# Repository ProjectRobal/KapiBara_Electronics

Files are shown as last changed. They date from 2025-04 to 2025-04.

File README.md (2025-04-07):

# KapiBara Electronics Design

That repository holds all the electronics for KapiBara robot. Everything was designed using KiCAD software.

## Boards

- KANGOO - a HAT that connects to Raspberry Pi 5. It delivers +5V using on board buck converter and gives Pi ability to communicate with CAN interface, it also has built in audio codec for microphones ( not used )
- KANGOO_1 - an evolution of KANGOO design it is HAT that connects to Modus extension board, like any other module
- MODUS - an extension board that connect every modules together using standard IDC connectors
- Modus_Extension_Template - a basic template creating standard module compatible with the MODUS board
- MEGANE - a module that handles DC motors control, odometry and orientation estimation using built in IMU and external Magnetrometer
- POWER - a board using for chargin robot's accumulator, it is also responsible for power delivering to entire system
- TWINGO - a module that handles reading state of external touch sensors
- TWINGO_v1.1 - a module that handles reading state of external touch plates, touch is detected by on board RC oscillatros ( not used )

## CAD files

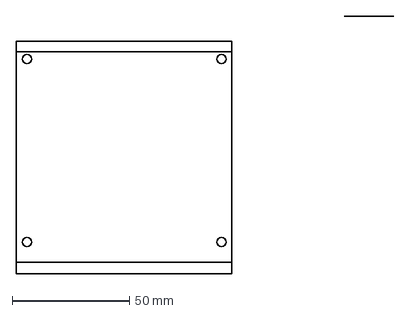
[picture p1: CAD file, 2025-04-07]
Modus/Modus/Modus_outline.dxf
160.8 x 109.7 mm

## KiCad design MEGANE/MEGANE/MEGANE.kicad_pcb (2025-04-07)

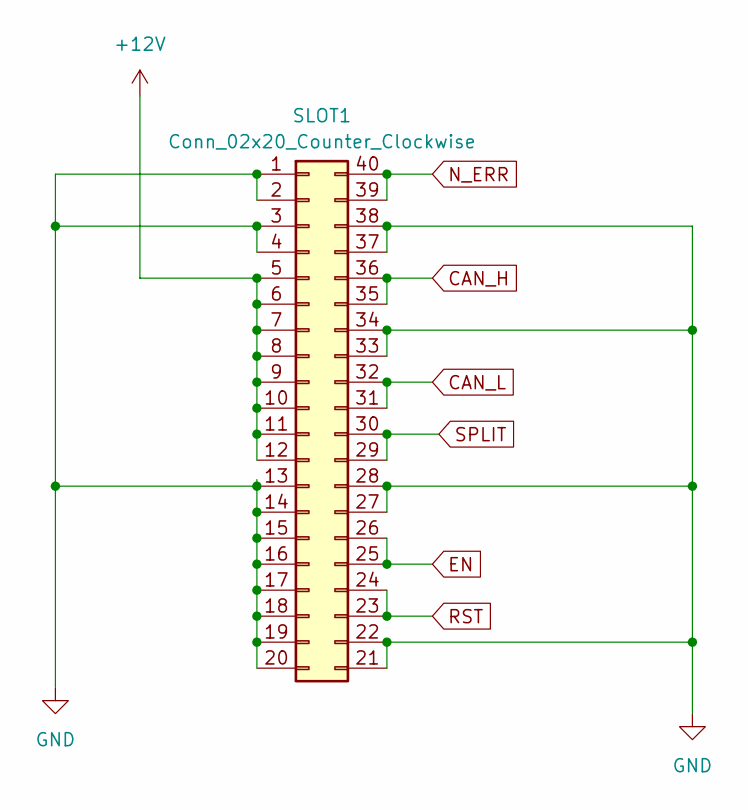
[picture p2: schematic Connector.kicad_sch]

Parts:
SLOT1: Conn_02x20_Counter_Clockwise; IDC-Header_2x20_P2.54mm_Horizontal

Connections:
+12V: SLOT1.5, SLOT1.6, SLOT1.7, SLOT1.8, SLOT1.9, SLOT1.10, SLOT1.11, SLOT1.12; also elsewhere on the board
CAN_H: SLOT1.35, SLOT1.36; also elsewhere on the board
CAN_L: SLOT1.31, SLOT1.32; also elsewhere on the board
EN: SLOT1.25, SLOT1.26; also elsewhere on the board
GND: SLOT1.1, SLOT1.2, SLOT1.3, SLOT1.4, SLOT1.13, SLOT1.14, SLOT1.15, SLOT1.16, SLOT1.17, SLOT1.18, SLOT1.19, SLOT1.20, SLOT1.21, SLOT1.22, SLOT1.27, SLOT1.28, SLOT1.33, SLOT1.34, SLOT1.37, SLOT1.38; also elsewhere on the board
N_ERR: SLOT1.39, SLOT1.40; also elsewhere on the board
RST: SLOT1.23, SLOT1.24; also elsewhere on the board
SPLIT: SLOT1.29, SLOT1.30; also elsewhere on the board

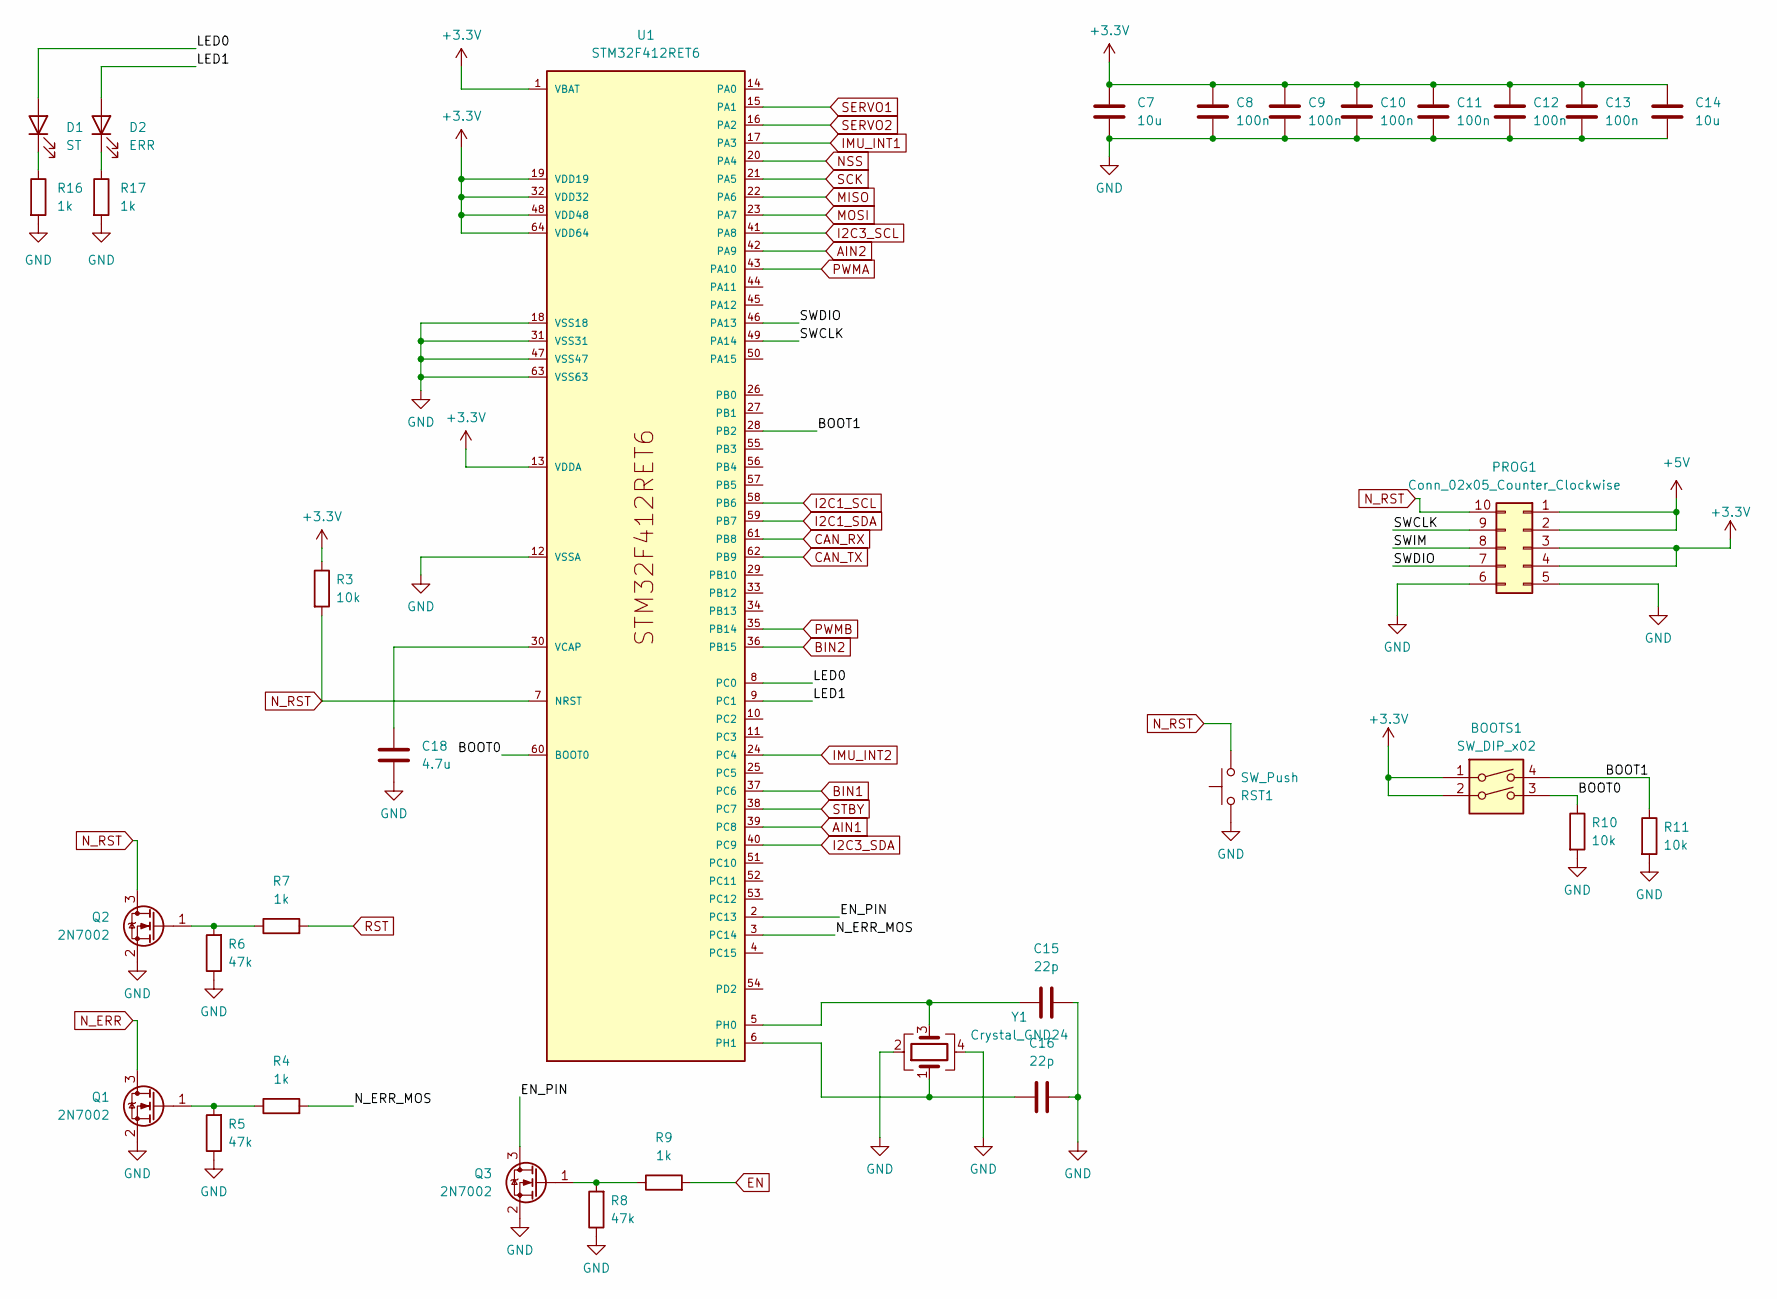
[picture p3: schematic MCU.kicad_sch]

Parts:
BOOTS1: SW_DIP_x02; SW_DIP_SPSTx02_Slide_6.7x6.64mm_W8.61mm_P2.54mm_LowProfile
C7, C14: 10u; C_0805_2012Metric_Pad1.18x1.45mm_HandSolder
C8, C9, C10, C11, C12, C13: 100n; C_0603_1608Metric_Pad1.08x0.95mm_HandSolder
C15, C16: 22p; C_0603_1608Metric_Pad1.08x0.95mm_HandSolder
C18: 4.7u; C_0805_2012Metric_Pad1.18x1.45mm_HandSolder
D1: ST; LED_0805_2012Metric_Pad1.15x1.40mm_HandSolder
D2: ERR; LED_0805_2012Metric_Pad1.15x1.40mm_HandSolder
PROG1: Conn_02x05_Counter_Clockwise; IDC-Header_2x05_P2.54mm_Horizontal
Q1, Q2, Q3: 2N7002; SOT-23
R3, R10, R11: 10k; R_0603_1608Metric_Pad0.98x0.95mm_HandSolder
R4, R7, R9, R16, R17: 1k; R_0603_1608Metric_Pad0.98x0.95mm_HandSolder
R5, R6, R8: 47k; R_0603_1608Metric_Pad0.98x0.95mm_HandSolder
RST1: SW_Push; SW_Tactile_SPST_Angled_PTS645Vx39-2LFS
U1: STM32F412RET6; LQFP-10X10-64
Y1: Crystal_GND24; Crystal_SMD_2520-4Pin_2.5x2.0mm

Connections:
+3.3V: BOOTS1.1, BOOTS1.2, C7.1, C8.1, C9.1, C10.1, C11.1, C12.1, C13.1, C14.1, PROG1.3, PROG1.4, R3.1, U1.1 (VBAT), U1.13 (VDDA), U1.19 (VDD19), U1.32 (VDD32), U1.48 (VDD48), U1.64 (VDD64); also elsewhere on the board
+5V: PROG1.1, PROG1.2; also elsewhere on the board
/MCU/BOOT0: BOOTS1.3, R10.1, U1.60 (BOOT0)
/MCU/BOOT1: BOOTS1.4, R11.1, U1.28 (PB2)
/MCU/EN_PIN: Q3.3 (D), U1.2 (PC13)
/MCU/LED0: D1.2 (A), U1.8 (PC0)
/MCU/LED1: D2.2 (A), U1.9 (PC1)
/MCU/N_ERR_MOS: R4.2, U1.3 (PC14)
/MCU/SWCLK: PROG1.9, U1.49 (PA14)
/MCU/SWDIO: PROG1.7, U1.46 (PA13)
/MCU/SWIM: PROG1.8
AIN1: U1.39 (PC8); also elsewhere on the board
AIN2: U1.42 (PA9); also elsewhere on the board
BIN1: U1.37 (PC6); also elsewhere on the board
BIN2: U1.36 (PB15); also elsewhere on the board
CAN_RX: U1.61 (PB8); also elsewhere on the board
CAN_TX: U1.62 (PB9); also elsewhere on the board
EN: R9.2; also elsewhere on the board
GND: C7.2, C8.2, C9.2, C10.2, C11.2, C12.2, C13.2, C14.2, C15.2, C16.2, C18.2, PROG1.5, PROG1.6, Q1.2 (S), Q2.2 (S), Q3.2 (S), R5.1, R6.1, R8.1, R10.2, R11.2, R16.2, R17.2, RST1.2, U1.12 (VSSA), U1.18 (VSS18), U1.31 (VSS31), U1.47 (VSS47), U1.63 (VSS63), Y1.2, Y1.4; also elsewhere on the board
I2C1_SCL: U1.58 (PB6); also elsewhere on the board
I2C1_SDA: U1.59 (PB7); also elsewhere on the board
I2C3_SCL: U1.41 (PA8); also elsewhere on the board
I2C3_SDA: U1.40 (PC9); also elsewhere on the board
IMU_INT1: U1.17 (PA3); also elsewhere on the board
IMU_INT2: U1.24 (PC4)
MISO: U1.22 (PA6)
MOSI: U1.23 (PA7)
NSS: U1.20 (PA4)
N_ERR: Q1.3 (D); also elsewhere on the board
N_RST: PROG1.10, Q2.3 (D), R3.2, RST1.1, U1.7 (NRST)
unnamed: D1.1 (K), R16.1
unnamed: D2.1 (K), R17.1
unnamed: Q1.1 (G), R4.1, R5.2
unnamed: Q2.1 (G), R6.2, R7.1
unnamed: Q3.1 (G), R8.2, R9.1
unnamed: C15.1, U1.5 (PH0), Y1.3
unnamed: C16.1, U1.6 (PH1), Y1.1
unnamed: C18.1, U1.30 (VCAP)
PWMA: U1.43 (PA10); also elsewhere on the board
PWMB: U1.35 (PB14); also elsewhere on the board
RST: R7.2; also elsewhere on the board
SCK: U1.21 (PA5)
SERVO1: U1.15 (PA1); also elsewhere on the board
SERVO2: U1.16 (PA2); also elsewhere on the board
STBY: U1.38 (PC7); also elsewhere on the board

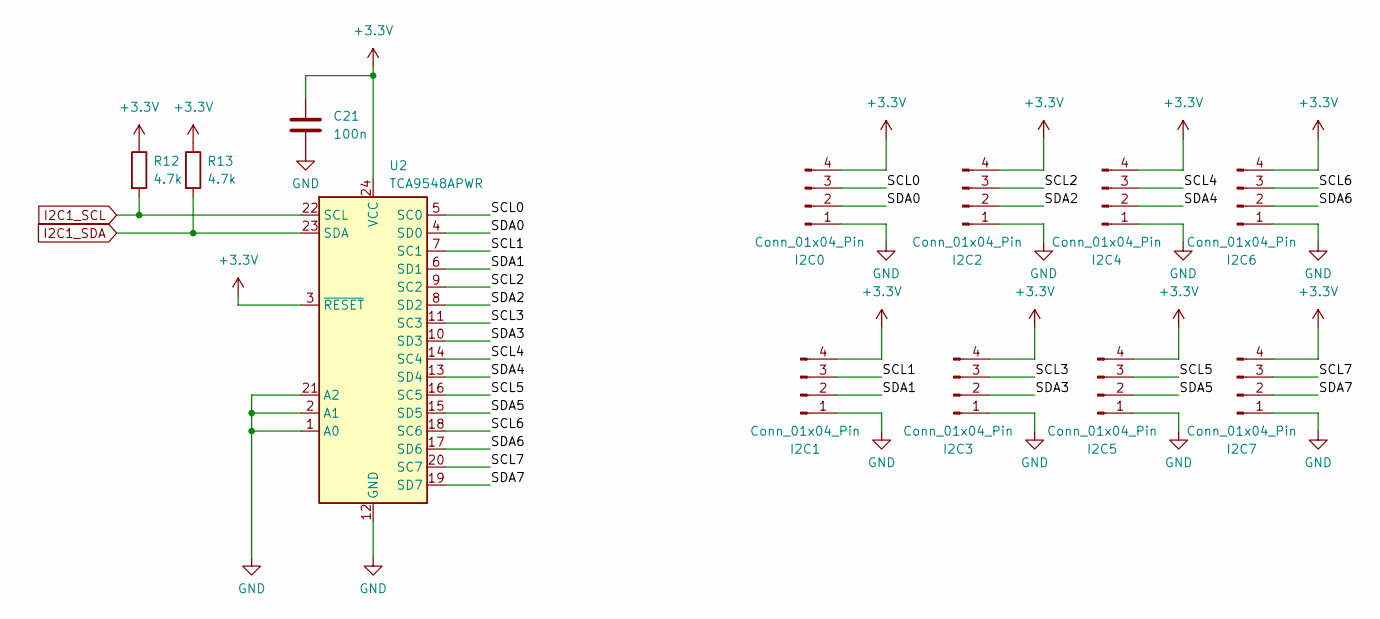
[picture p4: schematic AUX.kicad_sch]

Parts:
C21: 100n; C_0603_1608Metric_Pad1.08x0.95mm_HandSolder
I2C0, I2C1, I2C2, I2C3, I2C4, I2C5, I2C6, I2C7: Conn_01x04_Pin; JST_XH_B4B-XH-A_1x04_P2.50mm_Vertical
R12, R13: 4.7k; R_0603_1608Metric_Pad0.98x0.95mm_HandSolder
U2: TCA9548APWR; TSSOP-24_4.4x7.8mm_P0.65mm

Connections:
+3.3V: C21.2, I2C0.4, I2C1.4, I2C2.4, I2C3.4, I2C4.4, I2C5.4, I2C6.4, I2C7.4, R12.1, R13.1, U2.3 (~RESET), U2.24 (VCC); also elsewhere on the board
/AUX/SCL0: I2C0.3, U2.5 (SC0)
/AUX/SCL1: I2C1.3, U2.7 (SC1)
/AUX/SCL2: I2C2.3, U2.9 (SC2)
/AUX/SCL3: I2C3.3, U2.11 (SC3)
/AUX/SCL4: I2C4.3, U2.14 (SC4)
/AUX/SCL5: I2C5.3, U2.16 (SC5)
/AUX/SCL6: I2C6.3, U2.18 (SC6)
/AUX/SCL7: I2C7.3, U2.20 (SC7)
/AUX/SDA0: I2C0.2, U2.4 (SD0)
/AUX/SDA1: I2C1.2, U2.6 (SD1)
/AUX/SDA2: I2C2.2, U2.8 (SD2)
/AUX/SDA3: I2C3.2, U2.10 (SD3)
/AUX/SDA4: I2C4.2, U2.13 (SD4)
/AUX/SDA5: I2C5.2, U2.15 (SD5)
/AUX/SDA6: I2C6.2, U2.17 (SD6)
/AUX/SDA7: I2C7.2, U2.19 (SD7)
GND: C21.1, I2C0.1, I2C1.1, I2C2.1, I2C3.1, I2C4.1, I2C5.1, I2C6.1, I2C7.1, U2.1 (A0), U2.2 (A1), U2.12 (GND), U2.21 (A2); also elsewhere on the board
I2C1_SCL: R12.2, U2.22 (SCL); also elsewhere on the board
I2C1_SDA: R13.2, U2.23 (SDA); also elsewhere on the board

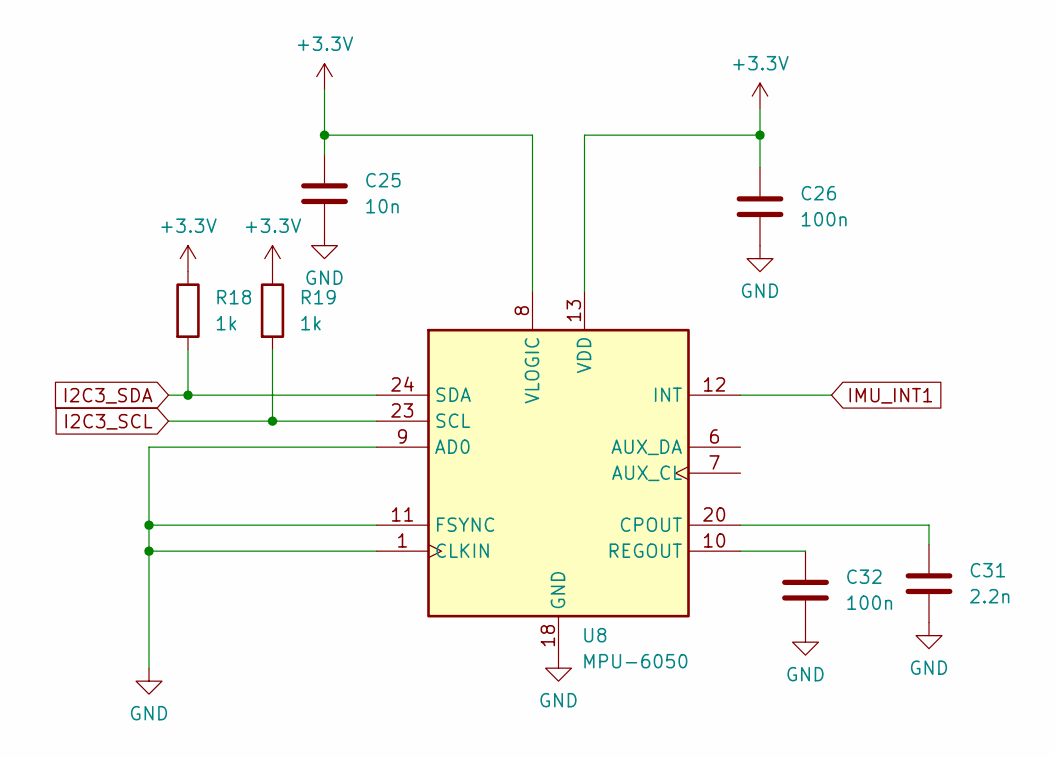
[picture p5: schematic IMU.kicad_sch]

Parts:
C25: 10n; C_0603_1608Metric_Pad1.08x0.95mm_HandSolder
C26, C32: 100n; C_0603_1608Metric_Pad1.08x0.95mm_HandSolder
C31: 2.2n; C_0603_1608Metric_Pad1.08x0.95mm_HandSolder
R18, R19: 1k; R_0603_1608Metric_Pad0.98x0.95mm_HandSolder
U8: MPU-6050; InvenSense_QFN-24_4x4mm_P0.5mm_NoMask

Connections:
+3.3V: C25.2, C26.2, R18.1, R19.1, U8.8 (VLOGIC), U8.13 (VDD); also elsewhere on the board
GND: C25.1, C26.1, C31.1, C32.1, U8.1 (CLKIN), U8.9 (AD0), U8.11 (FSYNC), U8.18 (GND); also elsewhere on the board
I2C3_SCL: R19.2, U8.23 (SCL); also elsewhere on the board
I2C3_SDA: R18.2, U8.24 (SDA); also elsewhere on the board
IMU_INT1: U8.12 (INT); also elsewhere on the board
unnamed: C31.2, U8.20 (CPOUT)
unnamed: C32.2, U8.10 (REGOUT)

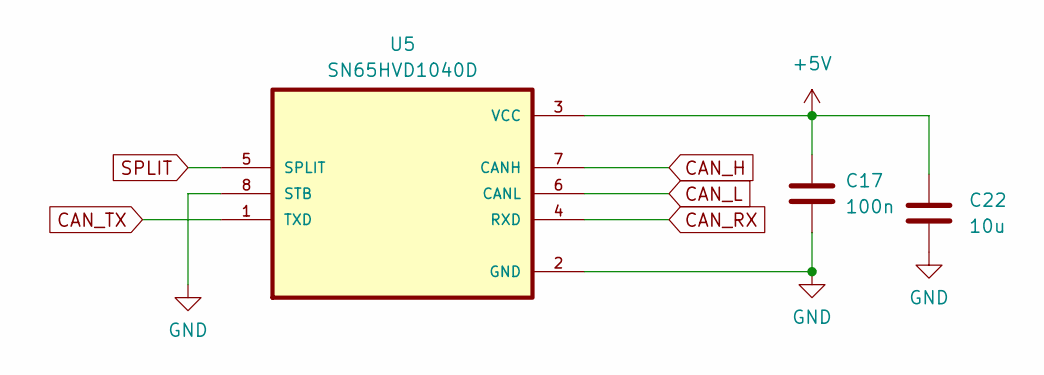
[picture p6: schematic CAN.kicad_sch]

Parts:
C17: 100n; C_0603_1608Metric_Pad1.08x0.95mm_HandSolder
C22: 10u; C_0805_2012Metric_Pad1.18x1.45mm_HandSolder
U5: SN65HVD1040D; SOIC127P599X175-8N

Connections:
+5V: C17.1, C22.1, U5.3 (VCC); also elsewhere on the board
CAN_H: U5.7 (CANH); also elsewhere on the board
CAN_L: U5.6 (CANL); also elsewhere on the board
CAN_RX: U5.4 (RXD); also elsewhere on the board
CAN_TX: U5.1 (TXD); also elsewhere on the board
GND: C17.2, C22.2, U5.2 (GND), U5.8 (STB); also elsewhere on the board
SPLIT: U5.5 (SPLIT); also elsewhere on the board

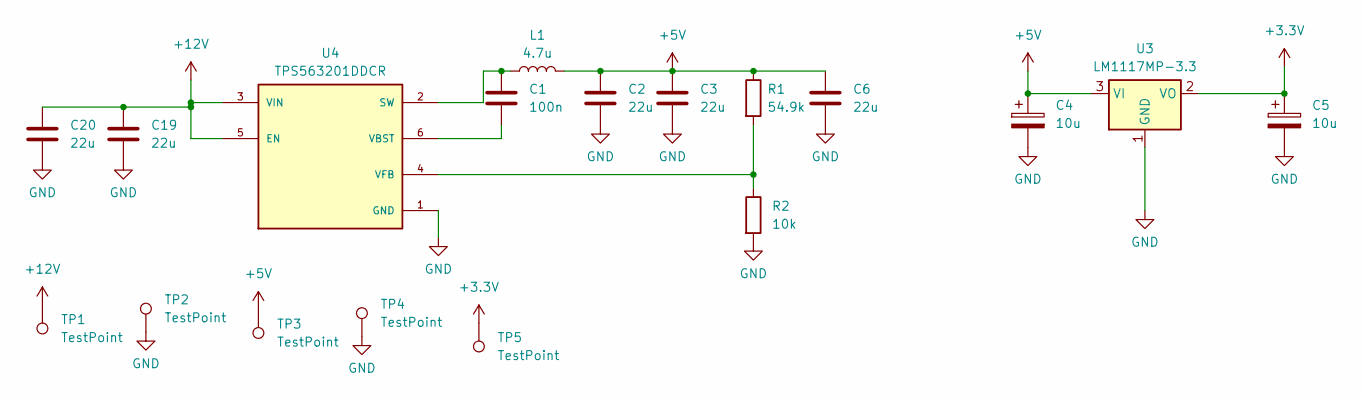
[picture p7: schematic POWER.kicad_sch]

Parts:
C1: 100n; C_0603_1608Metric_Pad1.08x0.95mm_HandSolder
C2, C3, C6, C19, C20: 22u; C_0805_2012Metric_Pad1.18x1.45mm_HandSolder
C4, C5: 10u; CP_EIA-3528-21_Kemet-B_Pad1.50x2.35mm_HandSolder
L1: 4.7u; L_Changjiang_FNR6045S
R1: 54.9k; R_0603_1608Metric_Pad0.98x0.95mm_HandSolder
R2: 10k; R_0603_1608Metric_Pad0.98x0.95mm_HandSolder
TP1, TP3, TP5: TestPoint; TestPoint_Pad_D3.0mm
TP2, TP4: TestPoint; TestPoint_Pad_3.0x3.0mm
U3: LM1117MP-3.3; SOT-223
U4: TPS563201DDCR; SOT95P280X110-6N; PARTREV December 2015

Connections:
+3.3V: C5.1, TP5.1, U3.2 (VO); also elsewhere on the board
+5V: C2.1, C3.1, C4.1, C6.1, L1.2, R1.1, TP3.1, U3.3 (VI); also elsewhere on the board
+12V: C19.1, C20.1, TP1.1, U4.3 (VIN), U4.5 (EN); also elsewhere on the board
GND: C2.2, C3.2, C4.2, C5.2, C6.2, C19.2, C20.2, R2.2, TP2.1, TP4.1, U3.1 (GND), U4.1 (GND); also elsewhere on the board
unnamed: C1.2, L1.1, U4.2 (SW)
unnamed: C1.1, U4.6 (VBST)
unnamed: R1.2, R2.1, U4.4 (VFB)

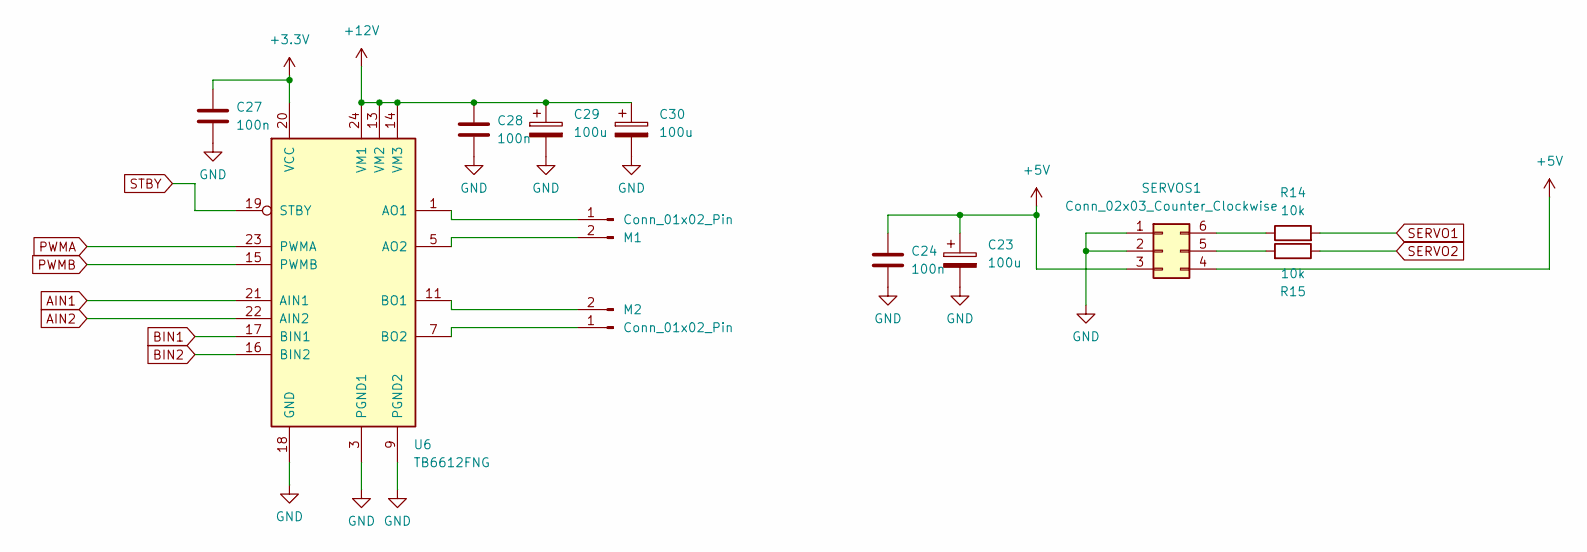
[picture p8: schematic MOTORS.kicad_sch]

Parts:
C23, C29, C30: 100u; CP_EIA-7132-28_AVX-C_Pad2.72x3.50mm_HandSolder
C24, C27, C28: 100n; C_0603_1608Metric_Pad1.08x0.95mm_HandSolder
M1, M2: Conn_01x02_Pin; AMASS_XT30PW-M_1x02_P2.50mm_Horizontal
R14, R15: 10k; R_0603_1608Metric_Pad0.98x0.95mm_HandSolder
SERVOS1: Conn_02x03_Counter_Clockwise; PinHeader_2x03_P2.54mm_Horizontal
U6: TB6612FNG; SSOP-24_5.3x8.2mm_P0.65mm

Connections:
+3.3V: C27.1, U6.20 (VCC); also elsewhere on the board
+5V: C23.1, C24.1, SERVOS1.3, SERVOS1.4; also elsewhere on the board
+12V: C28.1, C29.1, C30.1, U6.13 (VM2), U6.14 (VM3), U6.24 (VM1); also elsewhere on the board
AIN1: U6.21 (AIN1); also elsewhere on the board
AIN2: U6.22 (AIN2); also elsewhere on the board
BIN1: U6.17 (BIN1); also elsewhere on the board
BIN2: U6.16 (BIN2); also elsewhere on the board
GND: C23.2, C24.2, C27.2, C28.2, C29.2, C30.2, SERVOS1.1, SERVOS1.2, U6.3 (PGND1), U6.4 (PGND1), U6.9 (PGND2), U6.10 (PGND2), U6.18 (GND); also elsewhere on the board
unnamed: M1.1, U6.1 (AO1), U6.2 (AO1)
unnamed: M1.2, U6.5 (AO2), U6.6 (AO2)
unnamed: M2.1, U6.7 (BO2), U6.8 (BO2)
unnamed: M2.2, U6.11 (BO1), U6.12 (BO1)
unnamed: R15.2, SERVOS1.5
unnamed: R14.1, SERVOS1.6
PWMA: U6.23 (PWMA); also elsewhere on the board
PWMB: U6.15 (PWMB); also elsewhere on the board
SERVO1: R14.2; also elsewhere on the board
SERVO2: R15.1; also elsewhere on the board
STBY: U6.19 (STBY); also elsewhere on the board

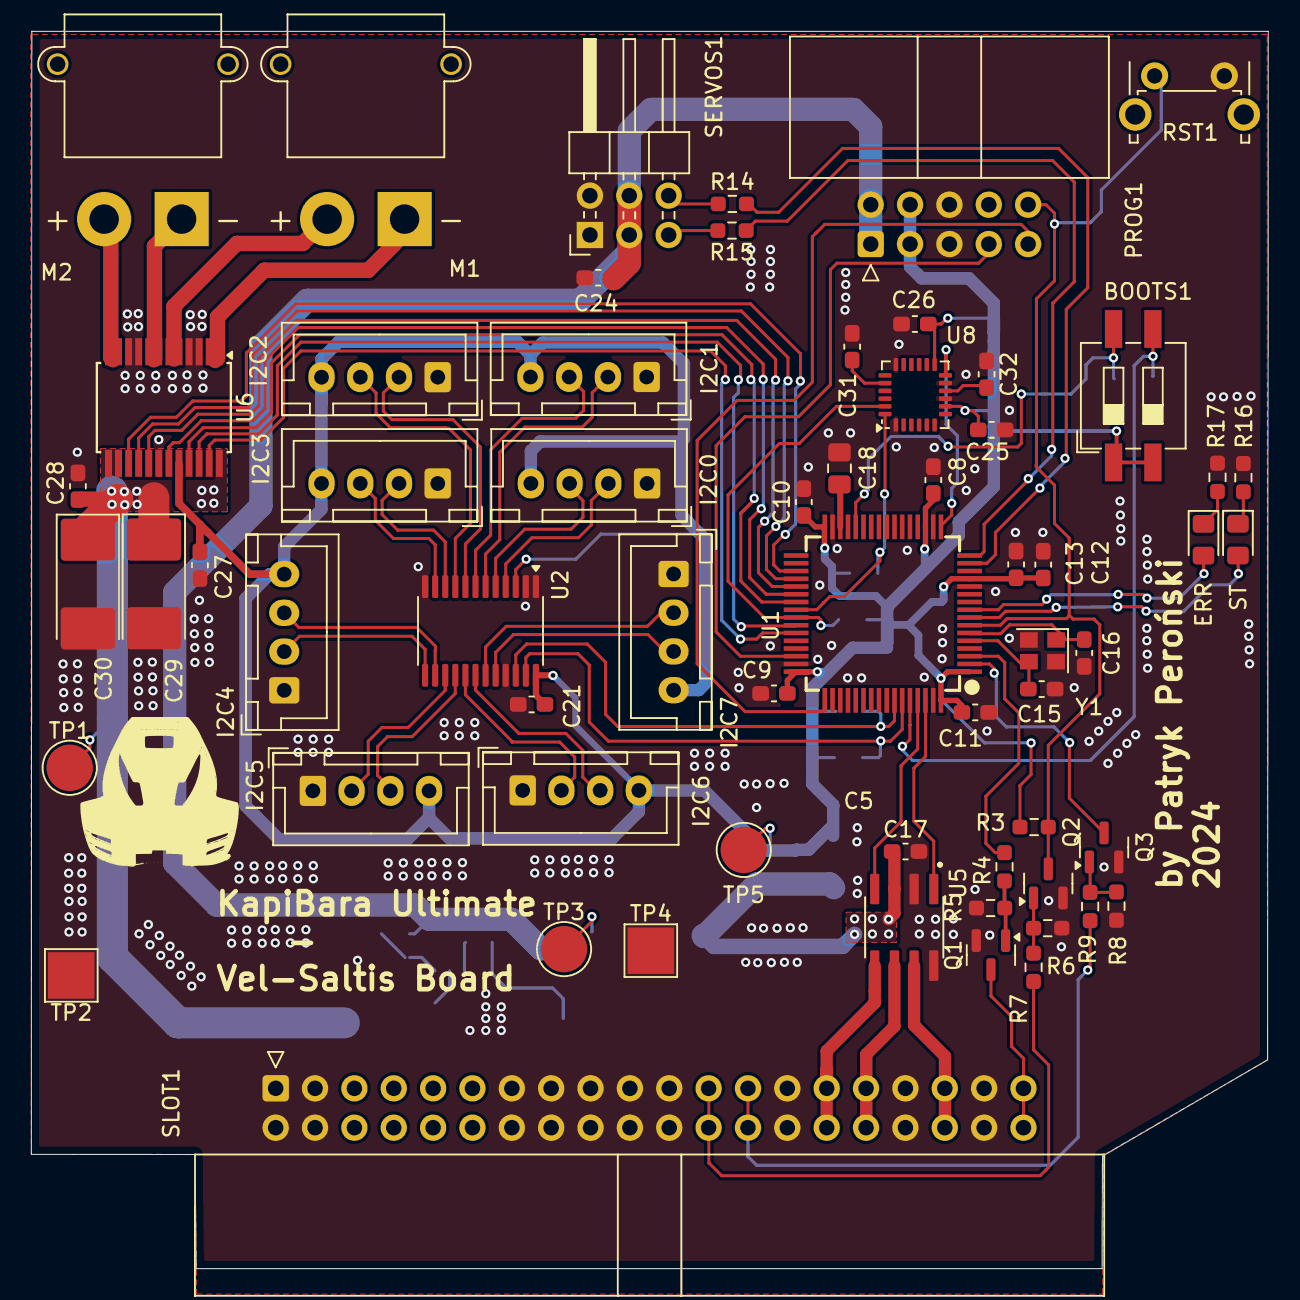
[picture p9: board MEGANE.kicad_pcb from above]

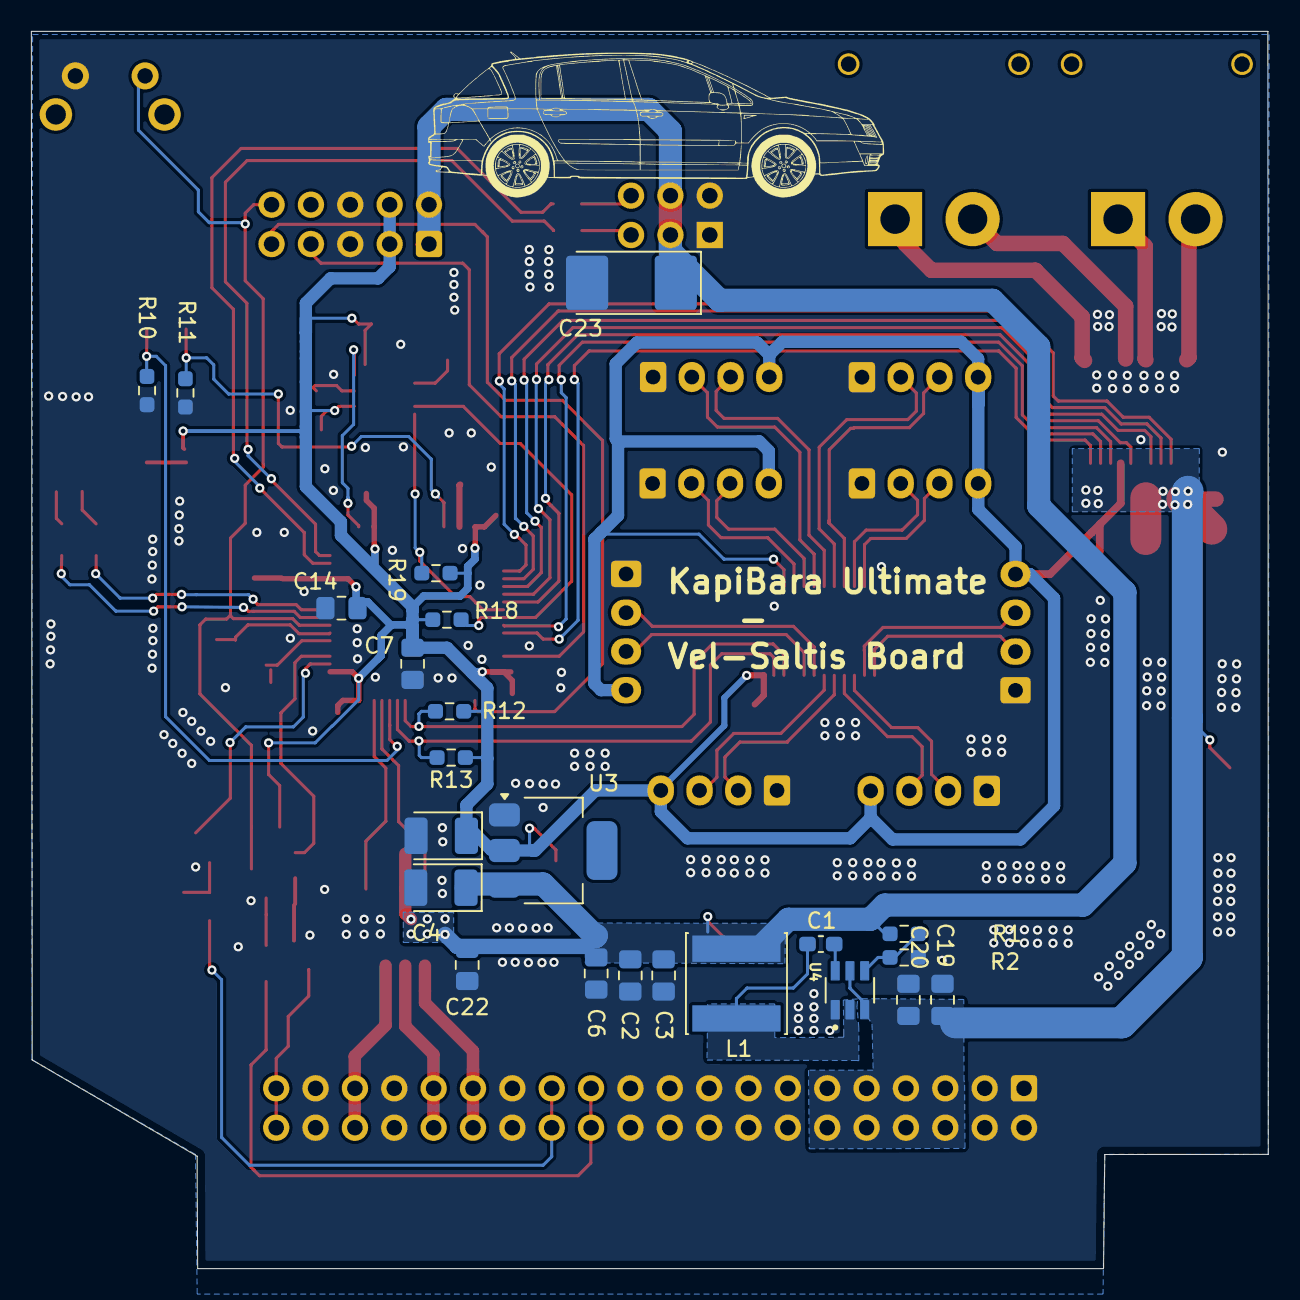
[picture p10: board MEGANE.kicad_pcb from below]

Board: 2 copper layers, 79.8 x 79.8 mm, 85 parts (23 on the bottom side), 70 nets.

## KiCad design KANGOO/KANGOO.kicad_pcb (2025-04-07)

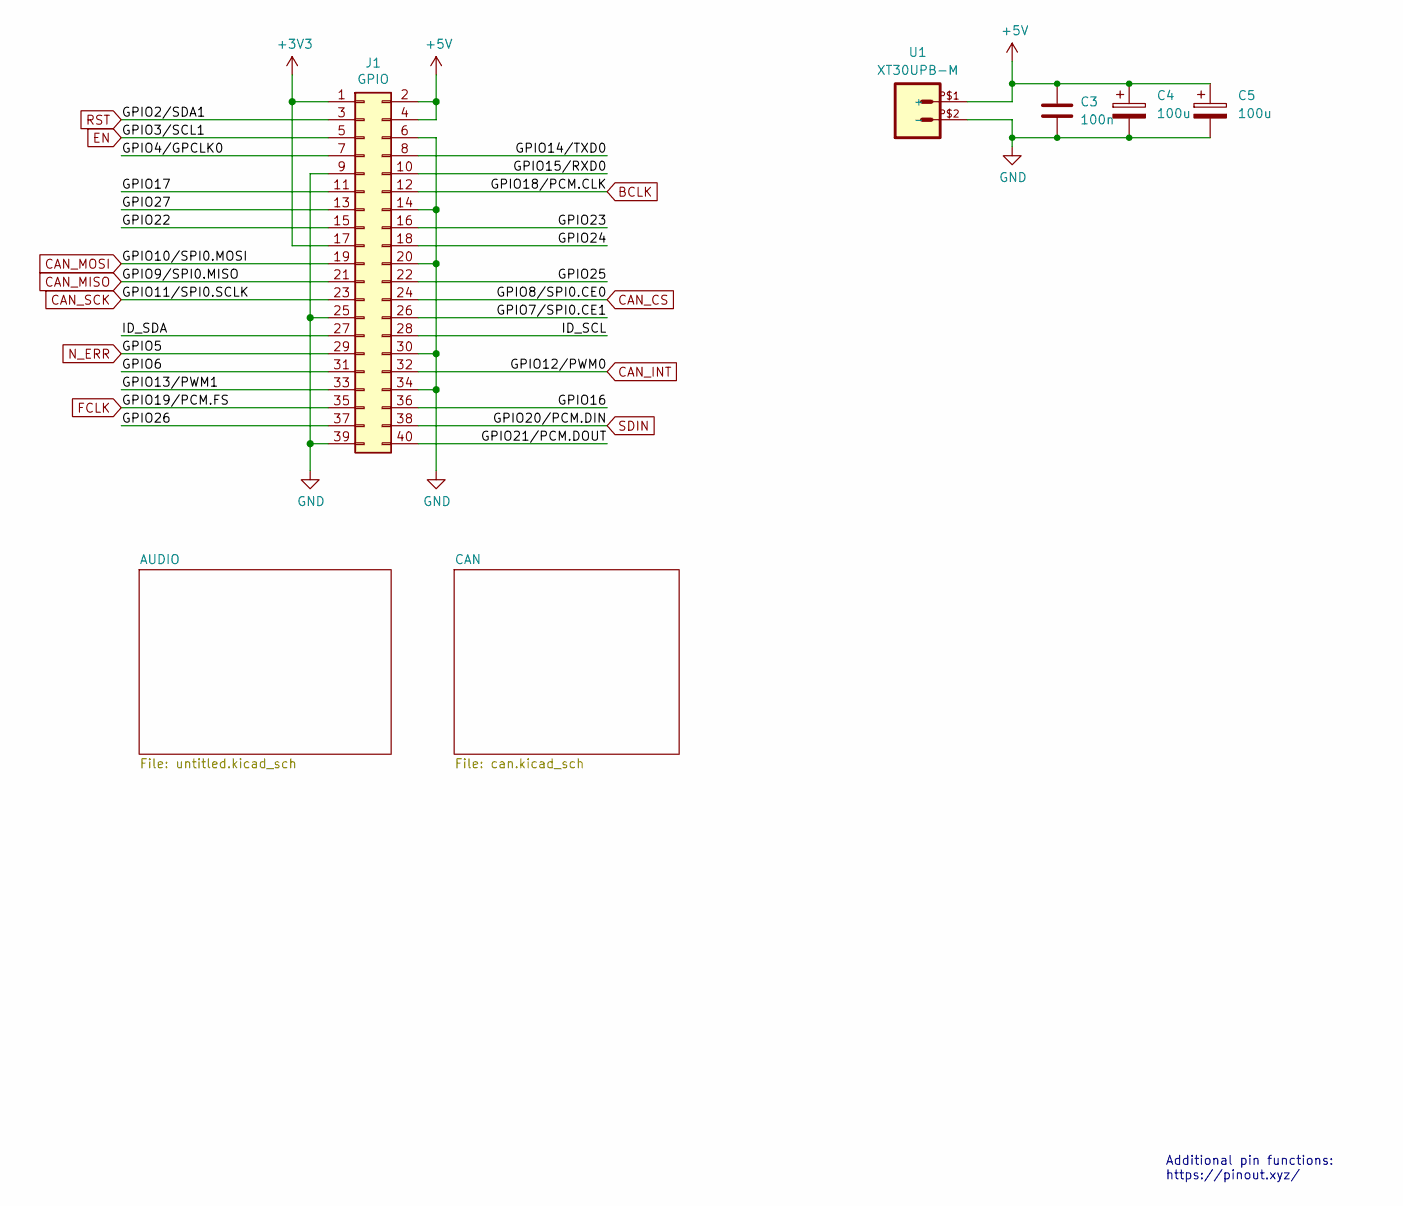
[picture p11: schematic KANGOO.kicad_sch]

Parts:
C3: 100n; C_0603_1608Metric_Pad1.08x0.95mm_HandSolder
C4, C5: 100u; CP_EIA-7132-28_AVX-C_Pad2.72x3.50mm_HandSolder
J1: GPIO; PinSocket_2x20_P2.54mm_Vertical
U1: XT30UPB-M

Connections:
+3V3: J1.1, J1.17
+5V: C3.1, C4.1, C5.1, J1.2, J1.4, U1.P$1 (+); also elsewhere on the board
/GPIO4/GPCLK0: J1.7
/GPIO6: J1.31
/GPIO7/SPI0.CE1: J1.26
/GPIO13/PWM1: J1.33
/GPIO14/TXD0: J1.8
/GPIO15/RXD0: J1.10
/GPIO16: J1.36
/GPIO17: J1.11
/GPIO21/PCM.DOUT: J1.40
/GPIO22: J1.15
/GPIO23: J1.16
/GPIO24: J1.18
/GPIO25: J1.22
/GPIO26: J1.37
/GPIO27: J1.13
/ID_SCL: J1.28
/ID_SDA: J1.27
BCLK: J1.12; also elsewhere on the board
CAN_CS: J1.24; also elsewhere on the board
CAN_INT: J1.32; also elsewhere on the board
CAN_MISO: J1.21; also elsewhere on the board
CAN_MOSI: J1.19; also elsewhere on the board
CAN_SCK: J1.23; also elsewhere on the board
EN: J1.5; also elsewhere on the board
FCLK: J1.35; also elsewhere on the board
GND: C3.2, C4.2, C5.2, J1.6, J1.9, J1.14, J1.20, J1.25, J1.30, J1.34, J1.39, U1.P$2 (-); also elsewhere on the board
N_ERR: J1.29; also elsewhere on the board
RST: J1.3; also elsewhere on the board
SDIN: J1.38; also elsewhere on the board

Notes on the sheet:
Additional pin functions: https://pinout.xyz/

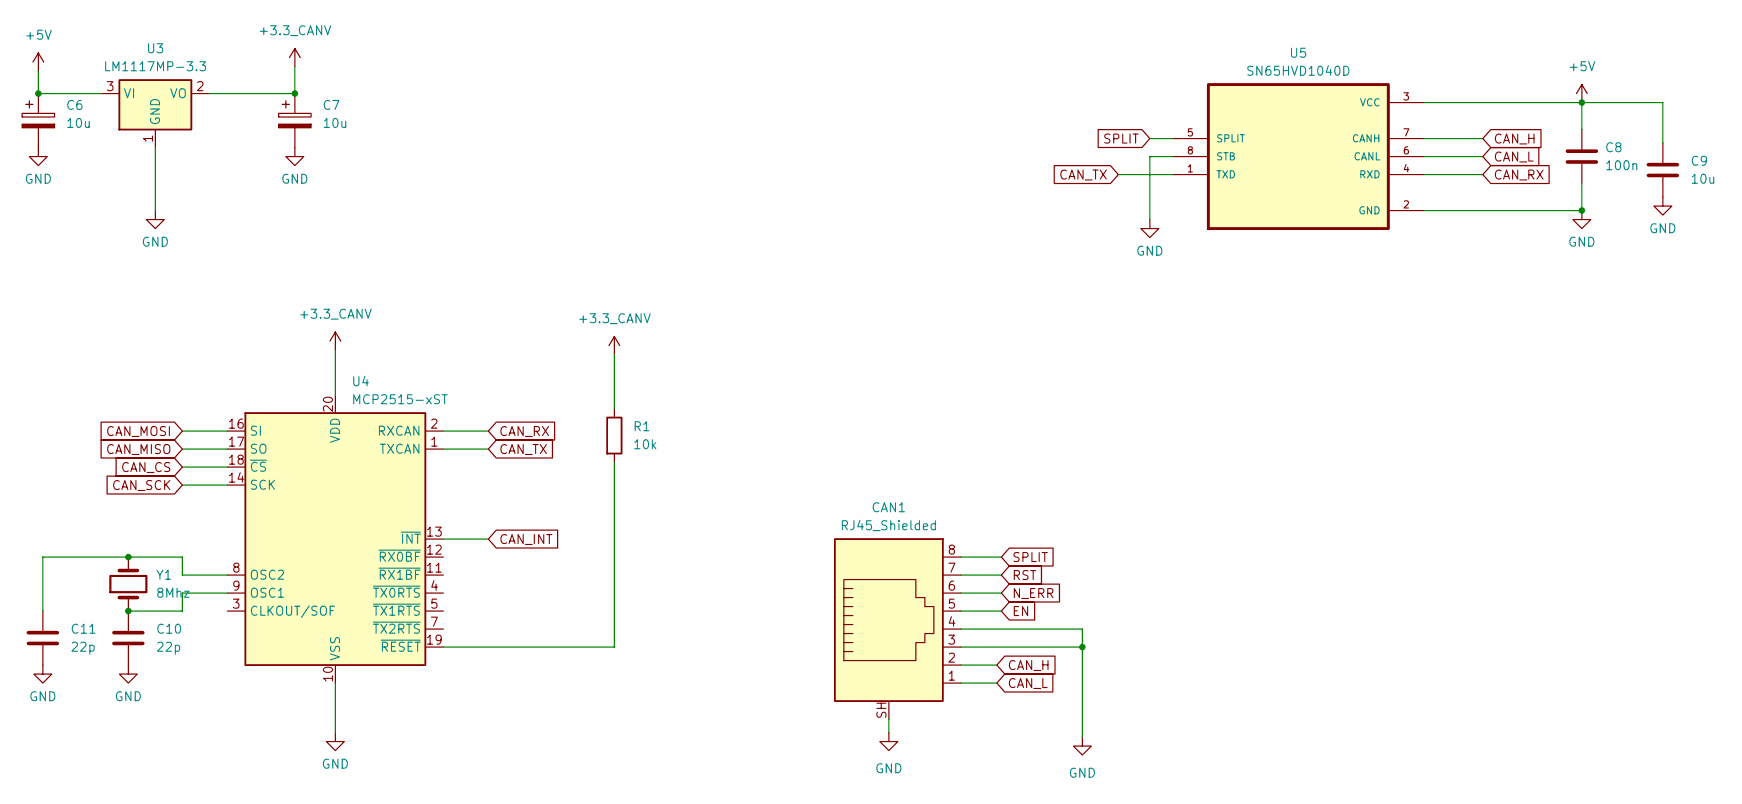
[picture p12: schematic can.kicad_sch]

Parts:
C6, C7: 10u; CP_EIA-3528-21_Kemet-B_Pad1.50x2.35mm_HandSolder
C8: 100n; C_0603_1608Metric_Pad1.08x0.95mm_HandSolder
C9: 10u; C_0805_2012Metric_Pad1.18x1.45mm_HandSolder
C10, C11: 22p; C_0603_1608Metric_Pad1.08x0.95mm_HandSolder
CAN1: RJ45_Shielded; RJ45_HALO_HFJ11-x2450HRL_Horizontal
R1: 10k; R_0603_1608Metric_Pad0.98x0.95mm_HandSolder
U3: LM1117MP-3.3; SOT-223
U4: MCP2515-xST; TSSOP-20_4.4x6.5mm_P0.65mm
U5: SN65HVD1040D; SOIC127P599X175-8N
Y1: 8Mhz; Crystal_HC49-U_Vertical

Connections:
+3.3_CANV: C7.1, R1.1, U3.2 (VO), U4.20 (VDD)
+5V: C6.1, C8.1, C9.1, U3.3 (VI), U5.3 (VCC); also elsewhere on the board
CAN_CS: U4.18 (~CS); also elsewhere on the board
CAN_H: CAN1.2, U5.7 (CANH)
CAN_INT: U4.13 (~INT); also elsewhere on the board
CAN_L: CAN1.1, U5.6 (CANL)
CAN_MISO: U4.17 (SO); also elsewhere on the board
CAN_MOSI: U4.16 (SI); also elsewhere on the board
CAN_RX: U4.2 (RXCAN), U5.4 (RXD)
CAN_SCK: U4.14 (SCK); also elsewhere on the board
CAN_TX: U4.1 (TXCAN), U5.1 (TXD)
EN: CAN1.5; also elsewhere on the board
GND: C6.2, C7.2, C8.2, C9.2, C10.2, C11.2, CAN1.3, CAN1.4, CAN1.SH, U3.1 (GND), U4.10 (VSS), U5.2 (GND), U5.8 (STB); also elsewhere on the board
N_ERR: CAN1.6; also elsewhere on the board
unnamed: C10.1, U4.9 (OSC1), Y1.1
unnamed: C11.1, U4.8 (OSC2), Y1.2
unnamed: R1.2, U4.19 (~RESET)
RST: CAN1.7; also elsewhere on the board
SPLIT: CAN1.8, U5.5 (SPLIT)

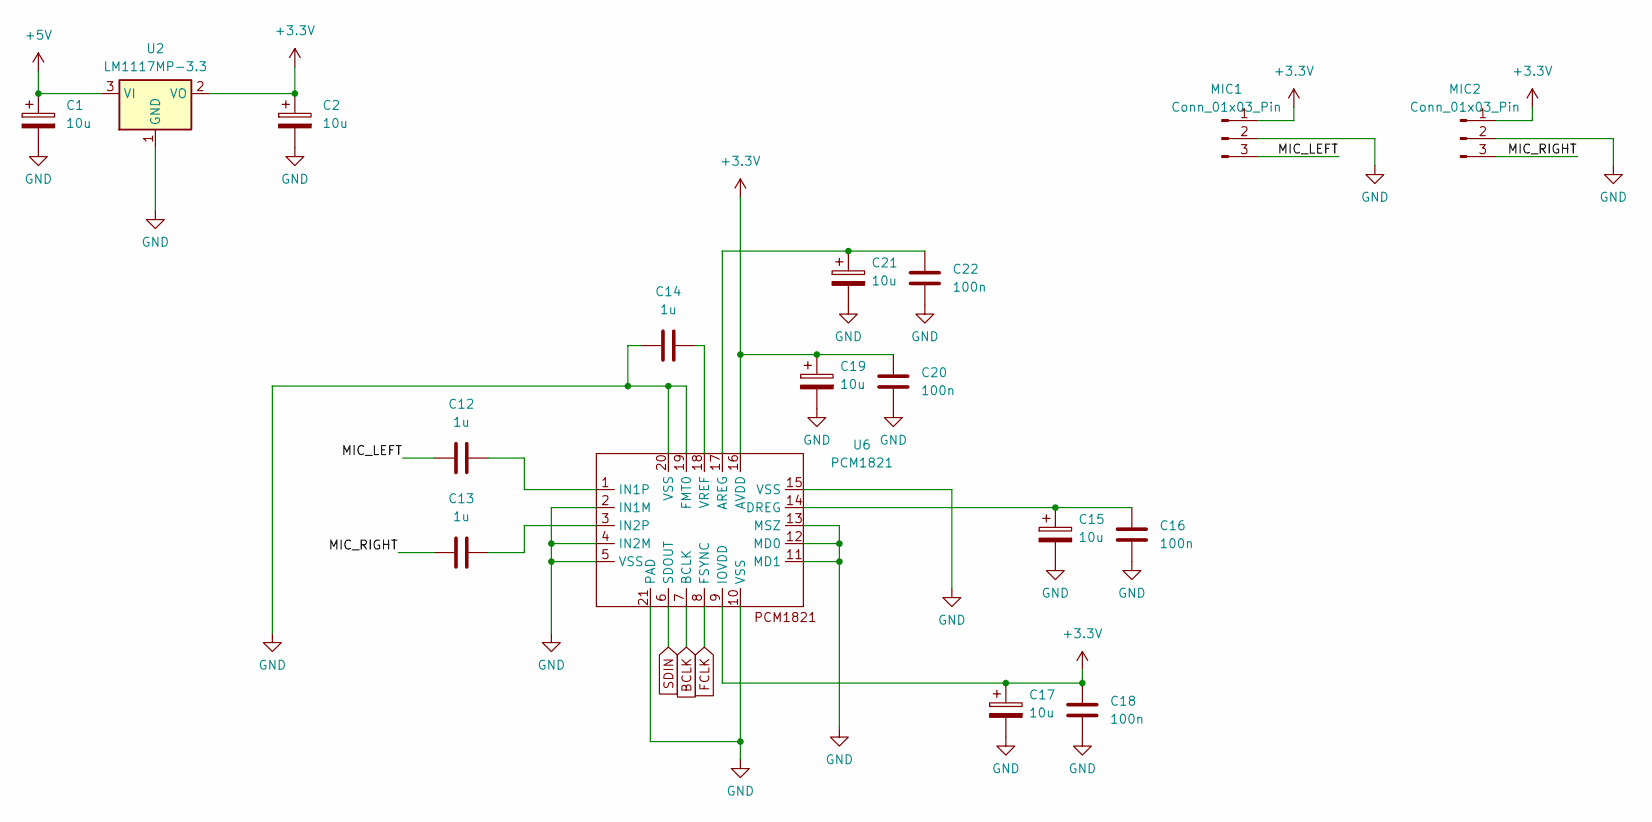
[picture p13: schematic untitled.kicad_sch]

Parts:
C1, C2, C15, C17, C19, C21: 10u; CP_EIA-3528-21_Kemet-B_Pad1.50x2.35mm_HandSolder
C12, C13, C14: 1u; C_0805_2012Metric_Pad1.18x1.45mm_HandSolder
C16, C18, C20, C22: 100n; C_0603_1608Metric_Pad1.08x0.95mm_HandSolder
MIC1, MIC2: Conn_01x03_Pin; JST_XH_B3B-XH-AM_1x03_P2.50mm_Vertical
U2: LM1117MP-3.3; SOT-223
U6: PCM1821; WQFN-16

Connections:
+3.3V: C2.1, C17.1, C18.1, C19.1, C20.1, MIC1.1, MIC2.1, U2.2 (VO), U6.9 (IOVDD), U6.16 (AVDD)
+5V: C1.1, U2.3 (VI); also elsewhere on the board
/AUDIO/MIC_LEFT: C12.1, MIC1.3
/AUDIO/MIC_RIGHT: C13.1, MIC2.3
BCLK: U6.7 (BCLK); also elsewhere on the board
FCLK: U6.8 (FSYNC); also elsewhere on the board
GND: C1.2, C2.2, C14.1, C15.2, C16.2, C17.2, C18.2, C19.2, C20.2, C21.2, C22.2, MIC1.2, MIC2.2, U2.1 (GND), U6.2 (IN1M), U6.4 (IN2M), U6.5 (VSS), U6.10 (VSS), U6.11 (MD1), U6.12 (MD0), U6.13 (MSZ), U6.15 (VSS), U6.19 (FMT0), U6.20 (VSS), U6.21 (PAD); also elsewhere on the board
unnamed: C21.1, C22.1, U6.17 (AREG)
unnamed: C15.1, C16.1, U6.14 (DREG)
unnamed: C12.2, U6.1 (IN1P)
unnamed: C13.2, U6.3 (IN2P)
unnamed: C14.2, U6.18 (VREF)
SDIN: U6.6 (SDOUT); also elsewhere on the board

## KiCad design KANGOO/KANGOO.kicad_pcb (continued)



Board: 2 copper layers, 68.6 x 56.0 mm, 36 parts (4 on the bottom side), 31 nets.

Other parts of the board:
MH1, MH2: MountingHole_2.7mm_M2.5

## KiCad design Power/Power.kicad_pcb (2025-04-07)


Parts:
BATT_IN1: XT30UPB-M
SYS_OUT1: XT30UPB-M
TP1: +12V; TestPoint_Pad_1.0x1.0mm
TP3: +5V; TestPoint_Pad_1.0x1.0mm
TP4: +3.3V; TestPoint_Pad_1.0x1.0mm
TP5, TP6, TP12: GND; TestPoint_Pad_1.0x1.0mm

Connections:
+3.3V: TP4.1; also elsewhere on the board
+5V: TP3.1; also elsewhere on the board
+12V: SYS_OUT1.P$1 (+), TP1.1; also elsewhere on the board
+BATT: BATT_IN1.P$1 (+); also elsewhere on the board
GND: BATT_IN1.P$2 (-), SYS_OUT1.P$2 (-), TP5.1, TP6.1, TP12.1; also elsewhere on the board


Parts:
C36: 10u; C_0603_1608Metric_Pad1.08x0.95mm_HandSolder
D4: USB; LED_0603_1608Metric_Pad1.05x0.95mm_HandSolder
PWR_SW1: Conn_01x02_Pin; JST_XH_B2B-XH-A_1x02_P2.50mm_Vertical
Q11, Q12: AONR21307; TRANS_AONR21307; PARTREV 1.1
Q13, Q14, Q15: 2N7002; SOT-23
R32: 15k; R_0603_1608Metric_Pad0.98x0.95mm_HandSolder
R33: 4.7k; R_0603_1608Metric_Pad0.98x0.95mm_HandSolder
R34, R35, R36: 47k; R_0603_1608Metric_Pad0.98x0.95mm_HandSolder
R37: 1k; R_0603_1608Metric_Pad0.98x0.95mm_HandSolder

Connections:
+12V: Q12.5_6_7_8; also elsewhere on the board
GND: C36.2, Q13.2 (S), Q14.2 (S), Q15.2 (S), R35.2, R36.2; also elsewhere on the board
unnamed: D4.1 (K), R32.1
unnamed: PWR_SW1.1, R37.1
unnamed: Q11.1, Q11.2, Q11.3, Q12.1, Q12.2, Q12.3, R34.1
unnamed: Q11.4, Q12.4, R33.1, R34.2
unnamed: Q13.3 (D), Q14.3 (D), R32.2, R33.2
unnamed: C36.1, Q14.1 (G), Q15.1 (G), R36.1, R37.2
PWR_SWITCH: Q13.1 (G), R35.1; also elsewhere on the board
STM_PWR_SWITCH_CLICK: Q15.3 (D); also elsewhere on the board
VCC: D4.2 (A), PWR_SW1.2, Q11.5_6_7_8; also elsewhere on the board


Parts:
AUX1: Conn_02x10_Counter_Clockwise; IDC-Header_2x10_P2.54mm_Vertical
C38: 100n; C_0603_1608Metric_Pad1.08x0.95mm_HandSolder
U3: SN65HVD1040D; SOIC127P599X175-8N

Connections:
+5V: C38.1, U3.3 (VCC); also elsewhere on the board
CAN_H: AUX1.5, AUX1.6, U3.7 (CANH)
CAN_L: AUX1.13, AUX1.14, U3.6 (CANL)
CAN_RX: U3.4 (RXD); also elsewhere on the board
CAN_TX: U3.1 (TXD); also elsewhere on the board
EN: AUX1.17, AUX1.18; also elsewhere on the board
GND: AUX1.3, AUX1.4, AUX1.7, AUX1.8, AUX1.11, AUX1.12, C38.2, U3.2 (GND), U3.8 (STB); also elsewhere on the board
SPLIT: AUX1.9, AUX1.10, AUX1.15, AUX1.16, U3.5 (SPLIT)


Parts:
C25: 1u; C_0805_2012Metric_Pad1.18x1.45mm_HandSolder
C26: 10n; C_0805_2012Metric_Pad1.18x1.45mm_HandSolder
D1: USB; LED_0603_1608Metric_Pad1.05x0.95mm_HandSolder
J1: USB_C_Receptacle_USB2.0_16P; USB_C_Receptacle_HRO_TYPE-C-31-M-12
Q6, Q7: AONR21307; TRANS_AONR21307; PARTREV 1.1
R14: 1Meg; R_0805_2012Metric_Pad1.20x1.40mm_HandSolder
R15: 47k; R_0603_1608Metric_Pad0.98x0.95mm_HandSolder
R16: 4.7k; R_0603_1608Metric_Pad0.98x0.95mm_HandSolder
R17: 15k; R_0603_1608Metric_Pad0.98x0.95mm_HandSolder
RISET1: NC; R_0603_1608Metric_Pad0.98x0.95mm_HandSolder
RVSET1: NC; R_0603_1608Metric_Pad0.98x0.95mm_HandSolder
TP2, TP7: +USB; TestPoint_Pad_1.0x1.0mm
U1: HUSB238; DFN-10-1EP_2.6x2.6mm_P0.5mm_EP1.3x2.2mm_ThermalVias

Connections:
+USB: Q7.5_6_7_8; also elsewhere on the board
GND: C25.2, C26.2, J1.A1 (GND), J1.A12 (GND), J1.B1 (GND), J1.B12 (GND), R14.2, RISET1.2, RVSET1.2, U1. (GND), U1.11; also elsewhere on the board
unnamed: C25.1, D1.2 (A), J1.A4 (VBUS), J1.A9 (VBUS), J1.B4 (VBUS), J1.B9 (VBUS), Q6.5_6_7_8, TP2.1, TP7.1, U1.1 (VIN)
unnamed: D1.1 (K), R17.1
unnamed: J1.A5 (CC1), U1.4 (CC1)
unnamed: J1.B5 (CC2), U1.5 (CC2)
unnamed: C26.1, J1.S1 (SHIELD), R14.1
unnamed: Q6.1, Q6.2, Q6.3, Q7.1, Q7.2, Q7.3, R15.1
unnamed: Q6.4, Q7.4, R15.2, R16.1
unnamed: J1.A6 (D+), J1.B6 (D+), U1.2 (D+)
unnamed: J1.A7 (D-), J1.B7 (D-), U1.3 (D-)
unnamed: R16.2, R17.2, U1.10 (GATE)
unnamed: RISET1.1, U1.9 (ISET)
unnamed: RVSET1.1, U1.8 (VSET)
SCL: U1.7 (SCL); also elsewhere on the board
SDA: U1.6 (SDA); also elsewhere on the board


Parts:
+AUX1: +AUX; TestPoint_Pad_2.5x2.5mm
-AUX1: +AUX; TestPoint_Pad_2.5x2.5mm
C40, C41, C43, C44, C45: 22u; C_0805_2012Metric_Pad1.18x1.45mm_HandSolder
C42: 100n; C_0603_1608Metric_Pad1.08x0.95mm_HandSolder
C46, C47: 10u; CP_EIA-3528-21_Kemet-B_Pad1.50x2.35mm_HandSolder
L2: 4.7u; L_Changjiang_FNR6045S
R30: 54.9k; R_0603_1608Metric_Pad0.98x0.95mm_HandSolder
R31: 10k; R_0603_1608Metric_Pad0.98x0.95mm_HandSolder
TP13: SW_5V; TestPoint_Pad_1.0x1.0mm
U4: TPS563201DDCR; SOT95P280X110-6N; PARTREV December 2015
U5: LM1117MP-3.3; SOT-223

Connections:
+3.3V: C47.1, U5.2 (VO); also elsewhere on the board
+5V: C43.1, C44.1, C45.1, C46.1, L2.2, R30.1, U5.3 (VI); also elsewhere on the board
+12V: C40.1, C41.1, U4.3 (VIN), U4.5 (EN); also elsewhere on the board
+USB: +AUX1.1; also elsewhere on the board
GND: -AUX1.1, C40.2, C41.2, C43.2, C44.2, C45.2, C46.2, C47.2, R31.2, U4.1 (GND), U5.1 (GND); also elsewhere on the board
unnamed: C42.2, L2.1, TP13.1, U4.2 (SW)
unnamed: C42.1, U4.6 (VBST)
unnamed: R30.2, R31.1, U4.4 (VFB)


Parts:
C27: 4.7u; C_0805_2012Metric_Pad1.18x1.45mm_HandSolder
C28, C29: 22p; C_0603_1608Metric_Pad1.08x0.95mm_HandSolder
C30, C37: 10u; C_0805_2012Metric_Pad1.18x1.45mm_HandSolder
C31, C32, C33, C34, C35: 100n; C_0603_1608Metric_Pad1.08x0.95mm_HandSolder
D2: F0; LED_0603_1608Metric_Pad1.05x0.95mm_HandSolder
D3: F1; LED_0603_1608Metric_Pad1.05x0.95mm_HandSolder
D5: CHG; LED_0603_1608Metric_Pad1.05x0.95mm_HandSolder
PROG1: Conn_02x04_Counter_Clockwise; PinHeader_2x04_P2.54mm_Vertical
Q8: 2N7002; SOT-23
R18, R19, R26, R27: 1k; R_0603_1608Metric_Pad0.98x0.95mm_HandSolder
R20, R21, R29, R38: 4.7k; R_0603_1608Metric_Pad0.98x0.95mm_HandSolder
R23: 100k; R_0603_1608Metric_Pad0.98x0.95mm_HandSolder
R24: 22k; R_0603_1608Metric_Pad0.98x0.95mm_HandSolder
R25: 10k; R_0603_1608Metric_Pad0.98x0.95mm_HandSolder
R28: 47k; R_0603_1608Metric_Pad0.98x0.95mm_HandSolder
RST1: SW_Push; SW_SPST_PTS647_Sx50
U2: STM32F412RET6; LQFP-10X10-64
Y1: Crystal_GND24; Crystal_SMD_2520-4Pin_2.5x2.0mm

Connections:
+3.3V: C30.1, C31.1, C32.1, C33.1, C34.1, C35.1, C37.1, D5.2 (A), PROG1.3, PROG1.4, R20.1, R21.1, R25.1, R29.1, R38.1, U2.1 (VBAT), U2.13 (VDDA), U2.19 (VDD19), U2.32 (VDD32), U2.48 (VDD48), U2.64 (VDD64); also elsewhere on the board
+12V: R23.1; also elsewhere on the board
/STM/BAT_SENSE: R23.2, R24.1, U2.27 (PB1)
/STM/LED0: D2.2 (A), U2.15 (PA1)
/STM/LED1: D3.2 (A), U2.16 (PA2)
/STM/SWCLK: PROG1.7, U2.49 (PA14)
/STM/SWDIO: PROG1.5, U2.46 (PA13)
ADAPTER_CURRENT_SENSE: U2.10 (PC2); also elsewhere on the board
BATTERY_CURRENT_SENSE: U2.9 (PC1); also elsewhere on the board
CAN_RX: U2.57 (PB5); also elsewhere on the board
CAN_TX: U2.58 (PB6); also elsewhere on the board
CHARGER_OK: R26.1, R29.2, U2.2 (PC13); also elsewhere on the board
EN: R27.2; also elsewhere on the board
GND: C27.2, C28.2, C29.2, C30.2, C31.2, C32.2, C33.2, C34.2, C35.2, C37.2, PROG1.1, PROG1.2, PROG1.6, Q8.2 (S), R18.2, R19.2, R24.2, R28.1, RST1.2, U2.12 (VSSA), U2.18 (VSS18), U2.28 (PB2), U2.31 (VSS31), U2.47 (VSS47), U2.60 (BOOT0), U2.63 (VSS63), Y1.2, Y1.4; also elsewhere on the board
N_RST: PROG1.8, R25.2, RST1.1, U2.7 (NRST)
unnamed: D2.1 (K), R18.1
unnamed: D3.1 (K), R19.1
unnamed: D5.1 (K), R26.2
unnamed: Q8.3 (D), U2.39 (PC8)
unnamed: Q8.1 (G), R27.1, R28.2
unnamed: C29.1, U2.5 (PH0), Y1.3
unnamed: C28.1, U2.6 (PH1), Y1.1
unnamed: C27.1, U2.30 (VCAP)
OTG: R38.2, U2.3 (PC14); also elsewhere on the board
POWER_SENSE: U2.8 (PC0); also elsewhere on the board
PROCHOT: U2.4 (PC15); also elsewhere on the board
PWR_SWITCH: U2.25 (PC5); also elsewhere on the board
SCL: R21.2, U2.61 (PB8); also elsewhere on the board
SDA: R20.2, U2.62 (PB9); also elsewhere on the board
STM_PWR_SWITCH_CLICK: U2.26 (PB0); also elsewhere on the board


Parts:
C1, C2: 47n; C_0805_2012Metric_Pad1.18x1.45mm_HandSolder
C3: 2.2u; C_0805_2012Metric_Pad1.18x1.45mm_HandSolder
C4: 100n; C_0603_1608Metric_Pad1.08x0.95mm_HandSolder
C5, C8: 1u; C_0805_2012Metric_Pad1.18x1.45mm_HandSolder
C6, C7, C18, C19, C20, C22: 100u; C_1206_3216Metric_Pad1.33x1.80mm_HandSolder
C9, C10: 33n; C_0603_1608Metric_Pad1.08x0.95mm_HandSolder
C11: 470n; C_0603_1608Metric_Pad1.08x0.95mm_HandSolder
C12, C13: 100p; C_0603_1608Metric_Pad1.08x0.95mm_HandSolder
C14: 3.3n; C_0805_2012Metric_Pad1.18x1.45mm_HandSolder
C15: 33p; C_0805_2012Metric_Pad1.18x1.45mm_HandSolder
C16: 1.2n; C_0603_1608Metric_Pad1.08x0.95mm_HandSolder
C17: 15p; C_0603_1608Metric_Pad1.08x0.95mm_HandSolder
C21: 22u; C_1206_3216Metric_Pad1.33x1.80mm_HandSolder
C23: 10n; C_0603_1608Metric_Pad1.08x0.95mm_HandSolder
C24: 1n; C_0603_1608Metric_Pad1.08x0.95mm_HandSolder
IC1: BQ25720RSNR; QFN40P400X400X80-33N-D; Mouser Part Number 595-BQ25720RSNR
L1: 2.2u; L_TaiTech_TMPC1265_13.5x12.5mm
Q1, Q2, Q3, Q4: CSD17578Q3A; TRANS_CSD18543Q3A
Q5: AONR21307; TRANS_AONR21307; PARTREV 1.1
R1, R2: 10; R_0603_1608Metric_Pad0.98x0.95mm_HandSolder
R3: 10; R_1206_3216Metric_Pad1.30x1.75mm_HandSolder
R4: 380k; R_0603_1608Metric_Pad0.98x0.95mm_HandSolder
R5: 220k; R_0603_1608Metric_Pad0.98x0.95mm_HandSolder
R6, R7: 4.99; R_0603_1608Metric_Pad0.98x0.95mm_HandSolder
R8: 1; R_0603_1608Metric_Pad0.98x0.95mm_HandSolder
R9: 270k; R_0603_1608Metric_Pad0.98x0.95mm_HandSolder
R10: 330k; R_0603_1608Metric_Pad0.98x0.95mm_HandSolder
R11: 16.9k; R_0603_1608Metric_Pad0.98x0.95mm_HandSolder
R12: 10k; R_0603_1608Metric_Pad0.98x0.95mm_HandSolder
R13: 30k; R_0603_1608Metric_Pad0.98x0.95mm_HandSolder
R22: 137k; R_0603_1608Metric_Pad0.98x0.95mm_HandSolder
RBatt1: 5m; R_2010_5025Metric_Pad1.40x2.65mm_HandSolder
RInput1: 5m; R_2010_5025Metric_Pad1.40x2.65mm_HandSolder
TP8, TP9, TP10, TP11: L1; TestPoint_Pad_1.0x1.0mm
TP14: RInput; TestPoint_Pad_1.0x1.0mm
TP15: BAT; TestPoint_Pad_1.0x1.0mm
TP16: VCC; TestPoint_Pad_1.0x1.0mm

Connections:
+BATT: C21.1, R2.1, RBatt1.2; also elsewhere on the board
+USB: C18.1, C19.1, C20.1, R6.1, R8.1, RInput1.1; also elsewhere on the board
/Charger/REGN: C3.1, IC1.28 (REGN), R3.1
/Charger/VDDA: C8.1, IC1.7 (VDDA), R3.2, R4.1, R9.1
ADAPTER_CURRENT_SENSE: C12.1, IC1.8 (IADPT), R22.1; also elsewhere on the board
BATTERY_CURRENT_SENSE: C13.1, IC1.9 (IBAT); also elsewhere on the board
CHARGER_OK: IC1.4 (CHRG_OK); also elsewhere on the board
CMP_OUT: IC1.15 (CMP_OUT)
GND: C3.2, C5.2, C6.2, C7.2, C8.2, C9.2, C10.2, C11.2, C12.2, C13.2, C14.2, C15.2, C16.2, C17.2, C18.2, C19.2, C20.2, C21.2, C22.2, C23.2, C24.2, IC1.14 (CMP_IN), IC1.27 (PGND), IC1.33 (EP), Q2.1 (S1), Q2.2 (S2), Q2.3 (S3), Q4.1 (S1), Q4.2 (S2), Q4.3 (S3), R5.2, R10.2, R13.2, R22.2; also elsewhere on the board
NET-(IC1-SW): Q2.11
unnamed: C5.1, Q5.5_6_7_8, R1.1, RBatt1.1, TP15.1
unnamed: C14.1, R11.2
unnamed: C16.1, R12.2
unnamed: C9.1, IC1.2 (ACN), R7.2
unnamed: C10.1, IC1.3 (ACP), R6.2
unnamed: C1.2, IC1.30 (BTST1)
unnamed: C2.2, IC1.25 (BTST2)
unnamed: IC1.18 (CELL_BATPRESZ), R9.2, R10.1
unnamed: C15.1, IC1.16 (COMP1), R11.1
unnamed: C17.1, IC1.17 (COMP2), R12.1
unnamed: IC1.31 (HIDRV1), Q1.4 (G)
unnamed: IC1.24 (HIDRV2), Q3.4 (G)
unnamed: IC1.6 (ILIM_HIZ), R4.2, R5.1
unnamed: IC1.29 (LODRV1), Q2.4 (G)
unnamed: IC1.26 (LODRV2), Q4.4 (G)
unnamed: C4.1, IC1.19 (SRN), R2.2
unnamed: C4.2, IC1.20 (SRP), R1.2
unnamed: C1.1, IC1.32 (SW1), L1.1, Q1.1 (S1), Q1.2 (S2), Q1.3 (S3), Q2.5 (D5), Q2.6 (D6), Q2.7 (D7), Q2.8 (D8), Q2.9, Q2.10, Q2.12, TP8.1, TP9.1
unnamed: C2.1, IC1.23 (SW2), L1.2, Q3.1 (S1), Q3.2 (S2), Q3.3 (S3), Q4.5 (D5), Q4.6 (D6), Q4.7 (D7), Q4.8 (D8), Q4.9, Q4.10, Q4.11, Q4.12, TP10.1, TP11.1
unnamed: C11.1, IC1.1 (VBUS), R8.2
unnamed: IC1.21 (~BATDRV), Q5.4
unnamed: C23.1, C24.1, Q1.5 (D5), Q1.6 (D6), Q1.7 (D7), Q1.8 (D8), Q1.9, Q1.10, Q1.11, Q1.12, R7.1, RInput1.2, TP14.1
OTG: IC1.5 (OTG/VAP/FRS); also elsewhere on the board
POWER_SENSE: IC1.10 (PSYS), R13.1; also elsewhere on the board
PROCHOT: IC1.11 (~PROCHOT); also elsewhere on the board
SCL: IC1.13 (SCL); also elsewhere on the board
SDA: IC1.12 (SDA); also elsewhere on the board
VCC: C6.1, C7.1, C22.1, IC1.22 (VSYS), Q3.5 (D5), Q3.6 (D6), Q3.7 (D7), Q3.8 (D8), Q3.9, Q3.10, Q3.11, Q3.12, Q5.1, Q5.2, Q5.3, TP16.1; also elsewhere on the board



Board: 2 copper layers, 41.1 x 88.0 mm, 140 parts (34 on the bottom side), 82 nets.

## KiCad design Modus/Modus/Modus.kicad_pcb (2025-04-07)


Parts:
AUX1, AUX2: Conn_02x10_Counter_Clockwise; IDC-Header_2x10_P2.54mm_Vertical
C2, C3: 4.7n; C_0805_2012Metric_Pad1.18x1.45mm_HandSolder
D1: NUP2105L; SOT-23
R2, R3, R4, R5: 60; R_0805_2012Metric_Pad1.20x1.40mm_HandSolder
TP1, TP2, TP3, TP4: TestPoint; TestPoint_Pad_D2.0mm

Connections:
CAN_H: AUX1.5, AUX1.6, AUX2.5, AUX2.6, D1.1 (K), R2.1, R4.1, TP1.1, TP2.1; also elsewhere on the board
CAN_L: AUX1.13, AUX1.14, AUX2.13, AUX2.14, D1.2 (K), R3.2, R5.2, TP3.1, TP4.1; also elsewhere on the board
EN: AUX1.17, AUX1.18, AUX2.17, AUX2.18; also elsewhere on the board
GND: AUX1.3, AUX1.4, AUX1.7, AUX1.8, AUX1.11, AUX1.12, AUX2.3, AUX2.4, AUX2.7, AUX2.8, AUX2.11, AUX2.12, C2.2, C3.2, D1.3 (A); also elsewhere on the board
N_ERR: AUX1.1, AUX1.2, AUX2.1, AUX2.2; also elsewhere on the board
RST: AUX1.19, AUX1.20, AUX2.19, AUX2.20; also elsewhere on the board
SPLIT: AUX1.9, AUX1.10, AUX1.15, AUX1.16, AUX2.9, AUX2.10, AUX2.15, AUX2.16, C2.1, C3.1, R2.2, R3.1, R4.2, R5.1; also elsewhere on the board


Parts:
+12V1: XT60-M; AMASS_XT60-M; PARTREV V1.2
GND1: TestPoint; TestPoint_Pad_3.0x3.0mm
P12V1: TestPoint; TestPoint_Pad_3.0x3.0mm
U1: XT30UPB-M

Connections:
+12V: +12V1.P (POS), P12V1.1, U1.P$1 (+); also elsewhere on the board
GND: +12V1.N (NEG), GND1.1, U1.P$2 (-); also elsewhere on the board


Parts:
SLOT1, SLOT2, SLOT3, SLOT4, SLOT5: Conn_02x20_Counter_Clockwise; IDC-Header_2x20_P2.54mm_Vertical

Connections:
+12V: SLOT1.5, SLOT1.6, SLOT1.7, SLOT1.8, SLOT1.9, SLOT1.10, SLOT1.11, SLOT1.12, SLOT2.5, SLOT2.6, SLOT2.7, SLOT2.8, SLOT2.9, SLOT2.10, SLOT2.11, SLOT2.12, SLOT3.5, SLOT3.6, SLOT3.7, SLOT3.8, SLOT3.9, SLOT3.10, SLOT3.11, SLOT3.12, SLOT4.5, SLOT4.6, SLOT4.7, SLOT4.8, SLOT4.9, SLOT4.10, SLOT4.11, SLOT4.12, SLOT5.5, SLOT5.6, SLOT5.7, SLOT5.8, SLOT5.9, SLOT5.10, SLOT5.11, SLOT5.12; also elsewhere on the board
CAN_H: SLOT1.35, SLOT1.36, SLOT2.35, SLOT2.36, SLOT3.35, SLOT3.36, SLOT4.35, SLOT4.36, SLOT5.35, SLOT5.36; also elsewhere on the board
CAN_L: SLOT1.31, SLOT1.32, SLOT2.31, SLOT2.32, SLOT3.31, SLOT3.32, SLOT4.31, SLOT4.32, SLOT5.31, SLOT5.32; also elsewhere on the board
EN: SLOT1.25, SLOT1.26, SLOT2.25, SLOT2.26, SLOT3.25, SLOT3.26, SLOT4.25, SLOT4.26, SLOT5.25, SLOT5.26; also elsewhere on the board
GND: SLOT1.1, SLOT1.2, SLOT1.3, SLOT1.4, SLOT1.13, SLOT1.14, SLOT1.15, SLOT1.16, SLOT1.17, SLOT1.18, SLOT1.19, SLOT1.20, SLOT1.21, SLOT1.22, SLOT1.27, SLOT1.28, SLOT1.33, SLOT1.34, SLOT1.37, SLOT1.38, SLOT2.1, SLOT2.2, SLOT2.3, SLOT2.4, SLOT2.13, SLOT2.14, SLOT2.15, SLOT2.16, SLOT2.17, SLOT2.18, SLOT2.19, SLOT2.20, SLOT2.21, SLOT2.22, SLOT2.27, SLOT2.28, SLOT2.33, SLOT2.34, SLOT2.37, SLOT2.38, SLOT3.1, SLOT3.2, SLOT3.3, SLOT3.4, SLOT3.13, SLOT3.14, SLOT3.15, SLOT3.16, SLOT3.17, SLOT3.18, SLOT3.19, SLOT3.20, SLOT3.21, SLOT3.22, SLOT3.27, SLOT3.28, SLOT3.33, SLOT3.34, SLOT3.37, SLOT3.38, SLOT4.1, SLOT4.2, SLOT4.3, SLOT4.4, SLOT4.13, SLOT4.14, SLOT4.15, SLOT4.16, SLOT4.17, SLOT4.18, SLOT4.19, SLOT4.20, SLOT4.21, SLOT4.22, SLOT4.27, SLOT4.28, SLOT4.33, SLOT4.34, SLOT4.37, SLOT4.38, SLOT5.1, SLOT5.2, SLOT5.3, SLOT5.4, SLOT5.13, SLOT5.14, SLOT5.15, SLOT5.16, SLOT5.17, SLOT5.18, SLOT5.19, SLOT5.20, SLOT5.21, SLOT5.22, SLOT5.27, SLOT5.28, SLOT5.33, SLOT5.34, SLOT5.37, SLOT5.38; also elsewhere on the board
N_ERR: SLOT1.39, SLOT1.40, SLOT2.39, SLOT2.40, SLOT3.39, SLOT3.40, SLOT4.39, SLOT4.40, SLOT5.39, SLOT5.40; also elsewhere on the board
RST: SLOT1.23, SLOT1.24, SLOT2.23, SLOT2.24, SLOT3.23, SLOT3.24, SLOT4.23, SLOT4.24, SLOT5.23, SLOT5.24; also elsewhere on the board
SPLIT: SLOT1.29, SLOT1.30, SLOT2.29, SLOT2.30, SLOT3.29, SLOT3.30, SLOT4.29, SLOT4.30, SLOT5.29, SLOT5.30; also elsewhere on the board


Board: 2 copper layers, 99.6 x 93.0 mm, 22 parts (1 on the bottom side), 8 nets.
